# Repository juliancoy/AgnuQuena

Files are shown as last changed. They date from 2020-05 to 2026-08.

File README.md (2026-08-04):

This is an OpenScad design of a Quena Andian flute. Is is parametric and split into 3 parts to allow to fit any 3d printer size.

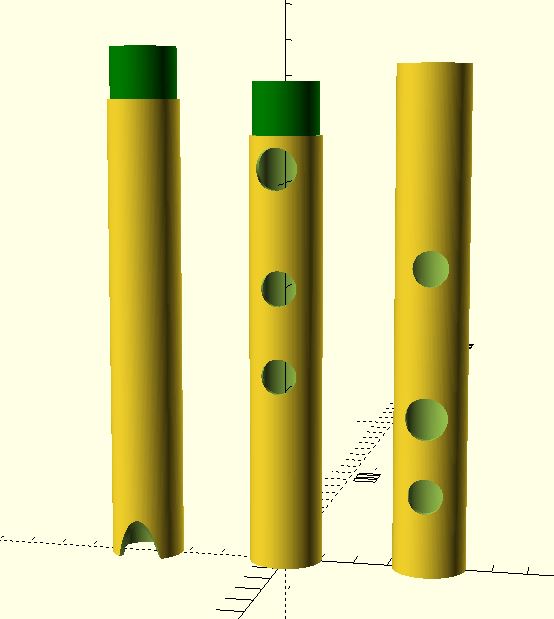
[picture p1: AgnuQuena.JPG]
GitHub Logo


## Production generation

The production flute is generated deterministically from
`designs/quena.json`. See [QUENA_GENERATION.md](QUENA_GENERATION.md) for the
rapid-iteration, validation, and STL export workflow.

```sh
make quena-generate
make quena-validate
make quena-export
```

To regenerate, validate, and slice the complete quena layout plus two-color and
single-filament print-in-place case variants for the Bambu Lab P1S, run:

```sh
make print-slice
```

The retained source projects, printable `.gcode.3mf` files, and plain G-code
are named `Quena`, `QuenaCase`, and `QuenaCaseSingleFilament` under
`bambu-slice-output/`, alongside job-specific slicer results and SHA-256
manifests. The printable 3MF files already contain the validated slice and open
directly in Preview, so printing does not depend on the desktop Slice action.
The two-color case confines all artwork
to the first `0.20 mm` layer, reducing the job to one material change. The
single-filament case preserves the
recessed logo and mandala/flourish engraving but omits the separate inlay mesh,
second filament, and prime tower. It is the unattended option for a printer
equipped with one AMS HT. Bambu Studio 2.8's mixed external/AMS mapping supports
assigning black filament 2 to External and yellow filament 1 to the AMS HT.
The printer prompts for the one manual external-path handoff before continuing
from the AMS. The source is pinned in the `BambuStudio` submodule and the scripts
invoke the native Linux CLI built directly from that revision. Run
`make bambu-studio-setup` once after cloning; its Ubuntu 24.04 Docker builder
keeps the large incremental build cache inside the ignored submodule build
directory, installs a project-local runtime, and installs the pinned official
Bambu networking plugin under the user's BambuStudio data directory. Existing
plugin files are retained in a timestamped backup. `make print-export` performs
the same canonical geometry and project generation without slicing, while
`make case-single-export` rebuilds only the single-filament case project.

## Browser CFD lab

`run.py` starts the lab and its automated Chrome test environment as two
Docker containers. Running it without arguments is equivalent to `up`.

```sh
python3 run.py
python3 run.py status
python3 run.py test --require-webgpu
python3 run.py down
```

The lab is served at <http://127.0.0.1:4173/acoustics.html>. Selenium listens
on port 4444, and its noVNC browser is available at <http://127.0.0.1:7900>.
The startup smoke test loads the lab through the Docker network, verifies its
CFD controls, advances the WebGPU clock when available, and writes a screenshot
to `build/selenium/acoustic-lab.png`.

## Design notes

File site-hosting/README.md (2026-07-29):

# Acoustic Lab hosting wrapper

This minimal Next application packages the static browser tools in `website/`
for OpenAI Sites. Before building or publishing, copy the current `website/`
contents into this directory's `public/` folder and copy
`.openai/hosting.json` into `.openai/hosting.json`.

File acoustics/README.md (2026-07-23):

# Vulkan Acoustic Simulation

This folder contains acoustic simulation tools for the quena geometry.

## Calibrated 1D Model

`quena_1d.py` reads the generated production manifest by default (with an
OpenSCAD fallback for historical work), applies calibrated per-hole corrections
where available, and writes pitch estimates that can be compared with
tune-check measurements.

Run the current worktree model:

```sh
python3 acoustics/quena_1d.py
```

To bypass the generated manifest and inspect a standalone SCAD file:

```sh
python3 acoustics/quena_1d.py --manifest "" --scad Quena.scad
```

Run a measured historical geometry and fit its correction from the saved
tune-check note:

```sh
python3 acoustics/quena_1d.py --commit a36f6253471d --fit-correction
```

Outputs:

- `acoustics/out/quena_1d_simulation_worktree.csv`
- `acoustics/out/quena_1d_simulation_worktree.json`

Use `--label current` or another label to choose a different output suffix.

This is the practical pitch estimator. It is calibrated and one-dimensional, so
it should be treated as an engineering model rather than a full fluid/acoustic
solver.

## Printable Materials

All acoustic runners accept `--material`. Available defaults:

```sh
python3 acoustics/quena_3d.py --list-materials
```

Supported built-in profiles include `pla`, `abs`, `petg`, `tpu`, `cf-pla`,
`cf-petg`, and `nylon`; `carbon-fiber` aliases to `cf-pla`. The material model
changes the simulated print result:
length scale, bore and tone-hole dimensional bias, end/tone-hole corrections,
and FDTD damping. It does not pretend the air column is made of plastic; for
stiff printed flutes the plastic mainly matters through geometry, edge finish,
wall loss, and compliance.

Example:

```sh
python3 acoustics/quena_3d.py --material petg --label petg_current
```

## Assembled Printed Shape

Export the fitted-together print shape and the matching internal air volume:

```sh
python3 acoustics/export_assembled.py
```

This writes ignored generated artifacts:

- `acoustics/out/assembled_quena.stl`
- `acoustics/out/assembled_air.stl`
- `acoustics/out/assembled_validation.json`

Use the air STL for the closest current simulation of the fitted print:

```sh
python3 acoustics/quena_3d.py --material abs --air-stl acoustics/out/assembled_air.stl --steps 4096 --label abs_air_stl_generated
```

The air STL is the acoustic domain. The plastic STL is useful for inspection and
validation, but simulating the plastic shell as the fluid domain would be wrong.

Current ABS assembled-air validation:

| note | predicted hz | predicted cents | measured cents |
| --- | ---: | ---: | ---: |
| G4 | 418.0214 | +111.27 | -1.3 |
| A4 | 422.4296 | -70.55 | -1.3 |
| B4 | 477.7188 | -57.6 | -41.3 |
| C5 | 513.1936 | -33.6 | -21.3 |
| D5 | 592.3994 | +14.88 | -11.3 |
| E5 | 675.0935 | +41.09 | -1.3 |
| F#5 | 771.279 | +71.7 | -21.3 |
| G5 | 751.0543 | -74.3 | -1.3 |

The assembled-air run currently has median absolute prediction error of
`55.8 cents` and RMS error of `65.5 cents` against the saved tune-check
measurements. Treat it as the current 3D fluid baseline for ABS in the exact
printed air shape, not yet as a final tuning oracle.

## 2D FDTD Cross-Section

`quena_2d.py` runs a scalar-pressure finite-difference simulation on a
longitudinal bore cross-section. The distal end and the active tone-hole opening
are pressure-release boundaries; the bore walls are reflective.

Run all notes:

```sh
python3 acoustics/quena_2d.py --label current
```

Run a single note while tuning model parameters:

```sh
python3 acoustics/quena_2d.py --note B4 --steps 32768
```

Outputs:

- `acoustics/out/quena_2d_simulation_current.csv`
- `acoustics/out/quena_2d_simulation_current.json`

This is a real time-domain simulation, but still a 2D approximation. It ignores
azimuthal tone-hole shape and external radiation impedance, so use it for
directional checks before treating it as a final tuning authority.

## 3D FDTD Bore Model

`quena_3d.py` is the CPU reference 3D fluid/acoustic simulation. It creates a
cylindrical bore air mask from the SCAD dimensions, uses reflective bore walls,
applies pressure-release openings for the distal end or active fingering hole,
injects an impulse, records receiver pressure, and reports FFT peaks.

Run all notes with the default coarse grid:

```sh
python3 acoustics/quena_3d.py --label current
```

Run a single note for faster iteration:

```sh
python3 acoustics/quena_3d.py --note B4 --steps 8192 --label b4_smoke
```

Outputs:

- `acoustics/out/quena_3d_simulation_current.csv`
- `acoustics/out/quena_3d_simulation_current.json`

The default grid is intentionally coarse enough to run on CPU. Reduce
`--cell-mm` only after validating runtime and memory use; 3D FDTD must keep
`--courant` below `1/sqrt(3)`.

### Breath source and environmental inputs

The 3D runner accepts physical breath parameters rather than an arbitrary
"soft/hard" label. Flow and jet area determine velocity and dynamic pressure;
vertical/lateral angles and lip distance determine source coupling. Air
temperature and relative humidity alter sound speed and therefore resonance.

```sh
python3 acoustics/quena_3d.py --note A4 --steps 8192 \
  --flow-l-min 12 --jet-width-mm 8 --jet-thickness-mm 1.2 \
  --vertical-angle-deg 15 --lateral-angle-deg 5 --lip-distance-mm 8 \
  --temperature-c 22 --relative-humidity-pct 50 --label a4_breath
```

This remains a linear scalar-pressure source-coupling model. It is appropriate
for resonance and sensitivity screening: breath quantity changes amplitude and
angle changes coupling, while temperature/humidity change frequency through
sound speed. It does **not** resolve the turbulent lip jet, vortex shedding,
self-sustained oscillation, pitch bending, or register selection. Those require
a transient compressible CFD model with the exterior mouthpiece/lip geometry;
do not interpret this source model as that CFD calculation.

Current coarse-grid validation:

```sh
python3 acoustics/quena_3d.py --steps 8192 --label current_coarse
```

This run completes on CPU and writes per-note pitch estimates. At the current
coarse resolution it is useful as a real 3D reference simulation, not a final
tuning oracle: the July 2026 comparison run had median absolute error around
`45 cents` and RMS error around `63 cents` for the idealized cylinder. The
assembled-air STL run above is the better baseline when checking the fitted
printed shape.

## Vulkan FDTD Setup

The Vulkan path is still a setup path for a future 3D FDTD simulation.

The compute kernel is `shaders/fdtd.comp`. It updates a scalar pressure field on
a 3D grid with a solid mask for printed material boundaries. Boundary neighbors
inside the solid mask mirror the center cell pressure, which approximates a hard
reflective wall.

Run the setup pass:

```sh
python3 acoustics/vulkan_fdtd.py --stl Quena.stl
```

That compiles the Vulkan shader with `glslc`, reads the STL bounds, checks the
3D Courant stability condition, and writes
`acoustics/out/simulation_manifest.json`.

Next implementation steps:

1. Voxelize the STL into the shader's `SolidMask` buffer.
2. Allocate Vulkan storage buffers for previous/current/next pressure fields.
3. Dispatch the compute shader for each timestep and record receiver samples.
4. FFT the receiver impulse response and compare peaks with measured notes.

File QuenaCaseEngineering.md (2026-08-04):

# Quena Case Engineering Notes

## Captive Print-in-Place Hinge

The complete case prints as two already-assembled moving bodies. Both shell
exteriors lie flat on the bed with the case opened exactly 180 degrees. The lid
carries a continuous axle captured inside seven closed bottom bearings, while
eight interleaved lid webs support the axle and limit axial travel. No pin
insertion, snap assembly, support material, or post-print joining is required.

Critical dimensions:

- Hinge axis: centered on the case seam
- Integral axle diameter: `4.6 mm`
- Axle print flat: `0.60 mm`
- Bearing exterior: fully round with a `0.40 mm` body-side starter web
- Outer axle ends: enclosed by solid, fully round `9.8 mm` lid barrels with
  `1.2 mm` clean-face overhangs
- Bearing bore: `5.20 mm`
- Radial print-in-place clearance: `0.30 mm`
- Bearing outside diameter: `9.8 mm`
- Minimum concentric bearing wall: `2.30 mm`
- Circular bore bridge span: `5.20 mm`
- Independent bearing width: `14.5 mm`
- Gap between alternating features: `1.0 mm`
- Rear-shell inset: `4.6 mm`
- Rear projection: `5.2 mm`
- Shell-edge gap in the print pose: `0.60 mm`

The axle retains its printer-facing flat inside the running bearings, while the
bearing exterior and both visible end barrels are fully round. Each stator
intersects the rear shell directly, without a rectangular backer that could
break its circular silhouette. The solid end barrels replace the exposed
D-flat axle stubs and tie directly into the outer
lid webs. A shallow tangent web connects the bearing's first layers back to the
body without entering the running bore. Each unsupported axle interval is only
one segment pitch (`15.5 mm`). The fully circular `5.20 mm` bore closes over a
short bridge span that remains below the validated `6.0 mm` support-free limit.
The radial clearance is deliberately larger than an assembled running fit
because the first motion must break minor extrusion wisps without welding the
joint.
Twist the two shell strips gently in opposite directions after cooling, then
exercise the hinge through its full travel before operating the latch.

## Nub-and-Knuckle Clasp

The latch is integral to the two case halves; there is no separately printed
latch. It follows the simplest molded harmonica-case pattern: two lid tongues
carry pronounced inward nubs, and the bottom front wall carries two matching
recesses. Pulling at the centered textured thumb zone releases the two points
progressively as the lid is opened.
Critical dimensions:

- Two `18 x 1.6 x 15.9 mm` lid cantilever tongues at `x=-72, +72 mm`,
  with `4.4 mm` widened bonded root haunches continuing toward the bed-facing
  lid back and an `11.5 mm` free flex span below them.
- `2.0 mm` nub/dimple radius and `1.25 mm` nub projection.
- `0.85 mm` bottom-wall recess depth.
- `0.40 mm` required release travel.
- Five low rounded grip ribs in a centered `30 mm` thumb zone.

The two nub spheres are added after all tongue, hinge, and ornament relief
booleans. No subtractive operation is allowed to flatten or hollow either nub.

Run `python3 tools/model_latch_snap.py --material all` to screen actuation. For
ABS, each tongue moves `0.40 mm`; the cantilever model predicts `0.73%` root
strain, `8.7-17.5 N` release force per point, and `4.13x` strain margin. The
conservative simultaneous two-point bound is `17.5-34.9 N`, though normal
opening should unzip the points progressively. All screened materials pass.
The full case is the physical check for closing alignment, user access, and
release force; no separate coupon meshes are maintained.

## Retention Features

Tube retention is built into five short curved sections of the bottom channel
border: two on Tube 1, two on Tube 2, and one on the mouthpiece. Each section
is `14 mm` long, rises `3.0 mm` above the stored-part centerline, and overlaps
the continuous bed by `0.4 mm` so it exports as one structural body. The
resulting normal-tube aperture has `0.34 mm` diametral interference: enough for
a light positive snap without forcing the entire channel length over the part.

The same border geometry, expanded by `0.25 mm`, is removed from the lid. This
keeps the closed outside envelope unchanged and prevents the raised bottom
features from loading the lid. Relative to the prior meshes, the bottom gains
`667.8 mm3` while the lid loses `686.8 mm3`; at `1.04 g/cm3` ABS density the
complete case changes by only `-0.02 g`.

The later round hinge-end enclosure adds about `1.05 g` net relative to that
pre-retention reference, keeping the complete case within `0.4%` of its former
mass while eliminating the exposed axle ends.

Run `python3 tools/simulate_case_inversion.py` for the inverted load screen.
At the default `42 g` stored mass, the closed case passes a `10 g` load with a
`7.4x` conservative latch-force margin. Physical insertion force, release
force, layer bonding, and fatigue still require a printed fit check.

## Channel Layout

Channel placement is based on the complete recess extents, including end and
connector clearance, rather than the nominal flute-part centers. This keeps
the recesses optically centered even though connector-bearing profiles are
asymmetric.

- P1 is a plain `241.25 mm` body. The `15 mm` tube-joint sleeve belongs to
  P2 and extends before its body, with the expanded case pocket on that end.
  Its closest assembled tone-hole edge is the D hole at `4.129 mm`; changing
  the breakpoint does not move any acoustically calibrated hole position.
- The long P1 recess is centered horizontally by its finished cut bounds.
- The short tube and mouthpiece recesses use equal `11.54 mm` left, middle, and
  right distribution gaps.
- Raised land between the two channel rows: `2.5 mm`.
- Raised perimeter land around the channel field: `2.5 mm` minimum.
- A single continuous `11.45 mm` bed forms the recesses and terminates `0.8 mm`
  beyond the nominal tube equator. The five localized snap-border sections
  extend that wrap to `3.0 mm`; there are no separate cantilever parts.

## Validation

Run:

```sh
python3 tools/render_case_assets.py --all-meshes
python3 tools/build_case_3mf.py
python3 tools/test_case_stls.py
python3 tools/test_case_browser.py
python3 tools/test_case_bambu.py
```

This checks:

- STL bounds and connected-component counts.
- Axle/bore clearance, concentric bearing wall, circular bridge span, alternating
  segment width, shell-edge bed gap, rear projection, axial web capture, and
  axle print flat, concentric bearing wall, starter web, and bed contact from the
  OpenSCAD parameters.
- The production STL contains exactly two watertight moving components, both
  touch `Z=0`, and the complete footprint stays inside `256 x 256 mm`.
- The bottom exterior retains a `14 mm` plan-view corner radius, `1.5 mm`
  bed-facing edge rounds, a border exactly `5 mm` inward, and three rendered
  mandalas with printable strokes and a two-layer recess floor.
- Closed clamshell solid overlap using OpenSCAD CSG intersection.
- Empty-case hinge sweep from `0` to `180` degrees around the actual hinge axis.
- Loaded hinge sweep over the same range using solid envelopes for all three
  flute parts, including connector bulges and transitions. The test repeats at
  18 combinations of the permitted axial, lateral, and lidward clearances.
- Chrome renders untransformed model-space STLs and checks their exact triangle
  BVHs at every whole-degree pose from `0` to `180`. A deliberate `4 mm`
  penetration must also register, proving that the detector is active.
- The browser keeps positive Z at the top of the view, lights both intentional
  friction-fit nub contacts while the case is closed, and removes those latch
  markers once the nubs release at `3 degrees`. Exact surface intersections
  elsewhere remain highlighted as line segments on the model.
- The browser loads the logo/title and mandala/flourish inlays as separate
  model-space meshes, using contrasting coral and gold materials rather than
  flattening either decoration into the blue shell material.
- The checksum-verified native Bambu Studio CLI opens and slices the project
  directly with the P1S profile, two ABS filaments, one colour change, and
  no generated support, brim, or skirt toolpaths. It checks that black is used
  only in the first `0.20 mm` layer and that the compact prime tower ends at
  `Z=0.2`.

The OpenSCAD and browser checks are required because Bullet/pybullet can miss
static concave mesh penetration and does not detect coplanar Z-fighting. The
browser therefore displays exact triangle contact separately from the two
intentional closed latch interferences. The browser regression caught a real
seven-point hinge collision at `25 degrees`; the lid relief now follows each
stator's complete circular envelope. A zero-depth hinge surface contact can be
visible without failing the rigid-envelope sweep; the failure threshold remains
`0.05 mm` of actual penetration.
The loaded sweep is a deterministic rigid-envelope interference screen. It does
not model flute bounce, elastic deformation, friction, wear, or latch failure;
inverted and shock retention remain separate engineering checks.

The larger shell's plan-view corner radius is `14 mm`. The alternating
axle-support tabs carry the same radius-to-width ratio into their shorter
visible profiles, producing an approximately `0.83 mm` base radius instead of
square shoulders. This proportional rounding does not expand the shallow
radial attachment land or alter the concentric bearing, bore, or
print-in-place clearance.

## Procedural Mandala and Flourish Panel

The lower panel in the open print pose carries three twelve-fold mandala
rosettes inside a rounded frame. Two symmetric vine-knot flourishes fill the
spaces between the rosettes. The design is generated entirely in
`QuenaCase.scad` from concentric rings, radial strokes, orbiting halos, curved
tendrils, and broad leaves, so it remains deterministic and scales with the
case rather than depending on another image asset. The frame centerline follows
the case outline exactly `5 mm` inward.

The single-filament body engraves the ornament `0.40 mm`, or two project
layers. The two-colour body instead uses a `0.20 mm` recess filled by the black
`QuenaCaseArtwork.stl` inlay. This preserves the case's face-down production
pose, reduces the two-colour job to one material change, and leaves at least
`2.40 mm` of solid roof. All
nominal strokes are `0.90 mm` wide, exceeding two line widths for the `0.4 mm`
nozzle. The recesses close without slicer-generated support, and the inlay
meets their floors exactly. The outside plan-view corner radius is `14 mm`,
and `1.5 mm` rounds soften both exposed bed-facing shell edges while retaining
flat first-layer contact. Internal fit, hinge, and latch geometry are unchanged.

## Two-Colour Case Artwork

`EurasianSynergyFlute_logo_2color.png` is the artwork source of truth. Running
`python3 tools/vectorize_case_logo.py` separates its original title and Eurasian
silhouette, removes details narrower than a `0.4 mm` nozzle, and deterministically
generates `generated/case_logo_title.svg`, `generated/case_logo_map.svg`, and
their measured source dimensions. The upper open-pose panel uses those traced
vectors rather than a substituted font or a hand-redrawn map.

The title remains `190 mm` wide and the map `84 mm` wide. A `0.84` vertical
scale fits the composition inside the long upper face while retaining at least a
`2.0 mm` rounded-edge margin. The single-filament logo remains engraved
`0.60 mm` deep for visibility. In the two-colour body, both logo and ornament
inlays are exactly one `0.20 mm` layer deep. Their tops meet the recess floors
exactly, so the black and yellow ABS fuse across a full planar interface.

The traced logo is rotated 180 degrees in the CAD source so it reads normally
when viewed through the base shell's exterior face, while remaining upright on
the upper panel like the display of an open laptop. It is not reflected, which
would reverse both the title and continent. The mandala and flourish inlay
shares the lid's `lid_in_print_pose()` transform and occupies the lower panel.
`QuenaCaseArtwork.stl` combines both black inlays, so they are translated and
aligned with `QuenaCaseTwoColorPrintInPlace.stl`; no slicer positioning is
required.

`QuenaCase.3mf` is the canonical native Bambu Studio two-colour P1S project.
`tools/build_case_3mf.py` creates its archive through the checksum-verified
project-local Bambu Studio CLI, then applies the locked placement and reviewed
print contract. It contains one assembly with:

- `QuenaCaseTwoColorPrintInPlace.stl` assigned to yellow ABS / AMS slot 1.
- `QuenaCaseArtwork.stl` assigned to black ABS / AMS slot 2.
- `0.20 mm` layers, two `0.42-0.45 mm` wall lines, two-layer top and bottom
  skins, `10%` rectilinear infill combined across compatible layers, and
  `0.15 mm` elephant-foot compensation. This reduces repeated perimeter and
  sparse-infill travel without changing the one-layer artwork, hinge, latch,
  or print-in-place clearances.
- The straight OpenSCAD shell is `0.827 mm`, the deposited envelope of the
  `0.42 + 0.45 mm` perimeter pair after Bambu's rounded-extrusion overlap at a
  `0.20 mm` layer height. The original `3 mm` structural margin remains local
  to the hinge, rim, and both friction-fit latch receivers; the mating nubs and
  their intentional closed-case collision are unchanged.
- The bottom channel bed meets the shell's inner face with a `0.04 mm`
  modeling overlap. Its printed edge is aligned with the perimeter, removing
  the open moat that previously separated the two regions.
- A continuous `0.827 mm` lip rises locally to `3.0 mm` past each tube
  centerline while the main bed and shell retain their original height. Its
  opening provides the light snap without isolated clips; the lid is lowered
  locally with `0.25 mm` matching relief around the complete profile.
- Broad outer walls run at a conservative `120 mm/s`, below the P1S standard
  profile's `200 mm/s`; the inherited `50%` small-perimeter rule keeps hinge,
  latch, and ornament details at `60 mm/s`.
- Supports, brims, and skirts disabled; a compact `20 mm` prime tower with a
  `1 mm` brim is limited to the active colour layer and ends at `Z=0.2`.

The two-colour slice has one material transition. With only one AMS HT,
map black filament 2 to External and yellow filament 1 to the AMS HT in the
Bambu Studio 2.8 send dialog. Its mixed external/AMS workflow pauses for the
operator to unload the unpowered external path, then continues from the AMS.
It is still not an unattended two-colour configuration,
but the single-layer artwork minimizes the intervention and purge waste.

`bambu-slice-output/QuenaCase.gcode.3mf` contains the validated slice and opens
directly in Preview. Use it for printing so the desktop application does not
need to run the unstable Linux GUI Slice action.

`QuenaCaseSingleFilament.3mf` is the one-material alternative. It contains only
`QuenaCasePrintInPlace.stl` on filament 1, so the logo and mandala/flourish
remain visible as recessed engraving instead of flush black inlays. It retains
the same placement, layers, walls, infill, and support-free contract while
disabling multi-material mode and the prime tower. Its validated G-code must
contain no second-tool request.

The project places the complete assembly at `X=2.275..253.725 mm` and its
sliced paths at `Y=70.787..184.735 mm`, clear of the P1S front-left exclusion
region and with the prime-tower area behind it. Inspect the first two sliced
layers before printing: only the first-layer artwork should be black, every
artwork island must bond to the yellow case at layer two, and the `0.60 mm`
hinge shell gap must remain open.

The automated Bambu slice produces `96` layers and one colour change. The
current estimate is about `111.39 g` of model ABS (`110.30 g` yellow and
`1.08 g` black), `112.06 g` including purge and prime-tower material, and
`4 h 30 min`; estimates can vary with Bambu Studio releases and printer
calibration.

## Print Practice

`QuenaCasePrintInPlace.stl` is the deeply engraved single-filament production
geometry. `QuenaCaseTwoColorPrintInPlace.stl` is the shallow-recess body for
`QuenaCase.3mf`; use `QuenaCaseSingleFilament.3mf` for a recessed one-material
finish. Both STLs are already oriented with both exterior backs on `Z=0`, side by
side, and the hinge captured at 180 degrees. Its `252.9 x 113.9 mm` footprint
fits the nominal `256 x 256 mm` bed with about `1.6 mm` of X margin per
side when centered. Disable brims, skirts, and automatic support; confirm the
retained P1S plate placement and printer-specific exclusion zones before
starting the full print.

`QuenaCaseBottom.stl` and `QuenaCaseLid.stl` are the canonical model-space
components used by both the browser and engineering validation. The combined
print-in-place STL remains separate because its lid must be rigidly rotated
180 degrees into the build-plate pose.

Use normal first-layer compensation rather than globally shrinking the hinge
gap. Avoid elephant-foot expansion into the 0.60 mm shell separation. After
the bed and part are fully cool, flex the two halves oppositely along the hinge
line to break any wisps, then rotate progressively from the center toward both
ends. Do not drive a blade or wire through the bearings.

- `QuenaCasePrintInPlace.stl`: `72294` triangles,
  `252.9 x 113.9 x 19.3 mm`, `2` connected components.
- `QuenaCaseTwoColorPrintInPlace.stl`: `72310` triangles,
  `252.9 x 113.9 x 19.3 mm`, `2` connected components.
- `QuenaCaseArtwork.stl`: `44502` triangles, `243.8 x 105.3 x 0.2 mm`,
  `31` connected artwork components.
- `QuenaCaseBottom.stl`: `17342` triangles,
  `252.9 x 61.3 x 19.3 mm`, `1` connected component.
- `QuenaCaseLid.stl`: `54960` triangles,
  `252.9 x 62.4 x 19.3 mm`, `1` connected component.
- `QuenaCaseLatch.stl`: `56.0 x 8.3 x 11.6 mm`.
- `QuenaCaseAssembly.stl`: `72294` triangles, `252.9 x 62.4 x 28.8 mm`.
- Closed overlap check: empty intersection.
- Hinge sweep check: passes from `0` to `180` degrees around
  `(0.00, -28.35, 14.40)`.
- Loaded hinge sweep: passes all `18` clearance-limit poses for all `3` stored
  part envelopes from `0` to `180` degrees.

Verify first-motion release, free rotation, and acceptable play on the full
print. If it fuses, adjust the canonical radial or axial clearance and
rerender; do not hand-fit the case or add a hidden slicer-only gap.

## Selective Output

Running `python3 tools/render_case_assets.py` produces only the primary
`QuenaCasePrintInPlace.stl`. Run it with `--list` to show every other mesh and
review sheet; those outputs are optional and selected with repeatable `--mesh`
and `--view` arguments. `--all-meshes` and `--all-views` are reserved for full
validation. Coupon outputs are not generated.

## Nine-View Review

Run:

```sh
python3 tools/render_case_assets.py --all-views
```

This regenerates:

- `QuenaCaseAssembly_9views.png`
- `QuenaCasePrintInPlace_9views.png`
- `QuenaCaseLidHingeCloseup_9views.png`

Each sheet is a 3x3 camera sweep at `1500 x 1101 px`. Use these views to catch
framing, hinge, and latch regressions before slicing.

The lid-hinge close-up sheet targets the integral axle, alternating support
webs, D-flat, and both axle ends without whole-part auto-framing.

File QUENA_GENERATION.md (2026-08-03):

# Quena generation workflow

`designs/quena.json` is the canonical production specification for the flute.
Do not hand-edit generated dimensions in `Quena.scad`,
`generated/quena_parameters.scad`, or `generated/quena_manifest.json`.

## Rapid iteration

1. Edit `designs/quena.json`.
2. Regenerate and validate the derived parameters:

   ```sh
   make quena-generate
   make quena-validate
   ```

3. Inspect the geometry and tuning report.
4. Export the three production components:

   ```sh
   make quena-export
   ```

The STL files and their SHA-256 production manifest are written under
`build/quena/`.

Use this command in CI or before slicing to detect generated files that do not
match the specification:

```sh
python3 tools/generate_quena.py --check
```

## What the generator owns

The generator derives:

- tuned acoustic and printable tube lengths;
- component split locations and maximum print height;
- lower-hand hole positions from the layout policy;
- measured-compensation hole diameters;
- OpenSCAD parameters shared by the flute and case;
- ergonomic hole diameter and width limits;
- hole edge, inter-hole ligament, and print-height validation;
- a machine-readable geometry and validation manifest.

The compensation model uses the low-frequency open-tone-hole shunt fit identified
in the specification, calibrated independently for each hole from the saved
prototype measurements. Each calibrated opening is solved directly against its
12-TET `target_note`; no legacy reference geometry defines the tuning target.
Calibration stores the printed prototype's actual acoustic hole position, so a
later body-length correction cannot rescale and invalidate that measurement.
When a guided run uses the removable headstock as a global tuner, its calibration
also stores `global_pitch_offset_cents`. The generator removes that shared offset
before fitting the hole correction, keeping base-note adjustment separate from
interval tuning.
Diameter results are rounded to the configured production increment. The fit is
based on Antoine Lefebvre's *Computational
Acoustic Methods for the Design of Woodwind Instruments*, equations 2.3.1–2.3.2:
<https://escholarship.mcgill.ca/concern/theses/0z708w835>.

## Design boundaries

Generation is deterministic and constraint-driven; it is not a substitute for
prototype measurement. After changing bore dimensions, material, hole profile,
or the lower-hand layout:

1. print a prototype;
2. record a guided tuning sample;
3. update the calibration measurements in the specification;
4. regenerate and compare the complete fingering set.

Use the fast one-dimensional model during iteration. Reserve the slower 2D/3D
models and physical prints for shortlisted geometries.

The current generator performs constrained geometric derivation and
measurement-calibrated diameter compensation. It does not claim to be a global
optimizer of the full fingering lattice. A future optimizer should consume this
same specification and manifest, evaluate all fingerings with a validated
transfer-matrix model, and return candidate specifications through the same
manufacturing checks.

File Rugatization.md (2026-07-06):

# Rugatization

## Goal

Raise the quality of AgnuQuena measurements by adding two connected systems:

1. A Vulkan-powered 3D acoustic simulation pipeline.
2. A Git-history measurement analysis pipeline that compares design dimensions with noted output pitches.

The simulation does not count as solved until it can produce testable pitch estimates from actual model geometry and compare those estimates with printed/measured results.

## Acceptance Criteria

- The tool can take `Quena.stl` or another generated STL as input.
- The STL is converted into a 3D solid/air simulation grid.
- A Vulkan compute shader runs a time-domain acoustic simulation over that grid.
- The simulation exports pressure samples from one or more receiver points.
- FFT or equivalent spectral analysis identifies candidate resonant frequencies.
- Simulated frequencies are compared against measured pitches from commit history and tuning files.
- Results are reproducible from scripts checked into the repo.

## Implementation Plan

1. Define simulation acceptance criteria and expected outputs.

   The pipeline should take an STL, simulate an impulse, output receiver pressure data, estimate resonance peaks, and compare those peaks against measured notes/history data.

2. Implement STL voxelization.

   Convert STL triangles into a 3D grid with a `solid_mask` buffer. This is the next hard blocker: without it, the shader has no real flute geometry.

3. Build Vulkan compute dispatch.

   Allocate `previous_pressure`, `current_pressure`, `next_pressure`, and `solid_mask` buffers. Dispatch the FDTD compute shader for many timesteps and ping-pong pressure buffers.

4. Add acoustic source and receiver modeling.

   Place a source near the mouthpiece or active edge. Place receivers near the bore end and optionally near tone holes. Export pressure samples as CSV first.

5. Analyze simulated response.

   Run FFT and peak detection over receiver impulse responses. Report candidate resonances in Hz and cents from expected notes.

6. Tie simulation results to Git-history measurements.

   Extend the measurement-history tooling so each commit/configuration can be associated with simulated pitch estimates and printed pitch measurements.

7. Validate against known measured pitches.

   Use pitch notes already present in `Quena.scad` and `Fife/tuning.csv` as the first benchmark. The first useful win condition is directional accuracy: geometry changes should move predicted resonances the same way measured prints do.

## Current State

- `tools/compare_measurements.py` extracts geometry, hole positions, pitch comments, and tuning CSV measurements across Git history.
- `measurements/history/*.csv` contains generated history-analysis outputs.
- `acoustics/quena_1d.py` provides a calibrated 1D bore model that reads SCAD/history geometry, emits pitch estimates, and compares them with tune-check measurements.
- `acoustics/quena_2d.py` runs a numpy-based 2D FDTD cross-section and exports FFT-derived pitch estimates for each fingering.
- `acoustics/quena_3d.py` runs a CPU 3D FDTD cylindrical-bore fluid/acoustic simulation and exports FFT-derived pitch estimates.
- `acoustics/materials.py` provides PLA, ABS, PETG, TPU, nylon, and carbon-fiber composite print profiles for dimensional bias, edge correction, wall loss, and damping.
- `acoustics/export_assembled.py` exports and validates fitted assembled plastic and internal-air STL files for exact-shape acoustic runs.
- `acoustics/quena_3d.py --air-stl acoustics/out/assembled_air.stl` voxelizes the fitted internal-air STL and runs the 3D fluid simulation on that exact air shape.
- `acoustics/shaders/fdtd.comp` contains a Vulkan compute shader for 3D scalar-pressure FDTD.
- `acoustics/vulkan_fdtd.py` compiles the shader, probes Vulkan devices, reads STL bounds, checks Courant stability, and writes a simulation manifest.
- Important geometry caveat: the current `Quena.stl` is a printable layout with separated parts, not a single assembled acoustic air column. Use `acoustics/export_assembled.py` to generate the fitted-together plastic and internal-air STLs for simulation.

## Latest ABS Exact-Shape Run

Command:

```sh
python3 acoustics/export_assembled.py
python3 acoustics/quena_3d.py --material abs --air-stl acoustics/out/assembled_air.stl --steps 4096 --label abs_air_stl_generated
```

Validation:

- Plastic STL: watertight, one component, 7188 faces.
- Internal-air STL: watertight, one component, 4406 faces.
- ABS assembled-air 3D FDTD: median absolute prediction error `55.8 cents`, RMS error `65.5 cents`.

Readings:

| note | predicted hz | predicted cents | measured cents |
| --- | ---: | ---: | ---: |
| G4 | 418.0214 | +111.27 | -1.3 |
| A4 | 422.4296 | -70.55 | -1.3 |
| B4 | 477.7188 | -57.6 | -41.3 |
| C5 | 513.1936 | -33.6 | -21.3 |
| D5 | 592.3994 | +14.88 | -11.3 |
| E5 | 675.0935 | +41.09 | -1.3 |
| F#5 | 771.279 | +71.7 | -21.3 |
| G5 | 751.0543 | -74.3 | -1.3 |

This is a real 3D fluid run over the fitted internal air volume. It is still a
coarse CPU model, so the result should guide the next simulation improvements
rather than directly drive hole changes.

## Progress Checklist

- [x] Define simulation acceptance criteria and expected outputs.
- [x] Add CPU 1D, 2D, and 3D reference simulations that export pitch estimates.
- [x] Export fitted assembled plastic and internal-air STLs.
- [x] Voxelize the assembled internal-air STL for CPU 3D FDTD.
- [x] Add acoustic source/receiver modeling and pressure sample export in CPU 2D/3D simulations.
- [x] Analyze simulated response into resonant pitch estimates.
- [x] Tie simulation results to Git-history and saved measurement CSVs.
- [x] Validate against known recorded pitch measurements.
- [ ] Implement STL voxelization into the Vulkan shader's `SolidMask` grid.
- [ ] Build Vulkan compute dispatch and pressure-buffer ping-pong.

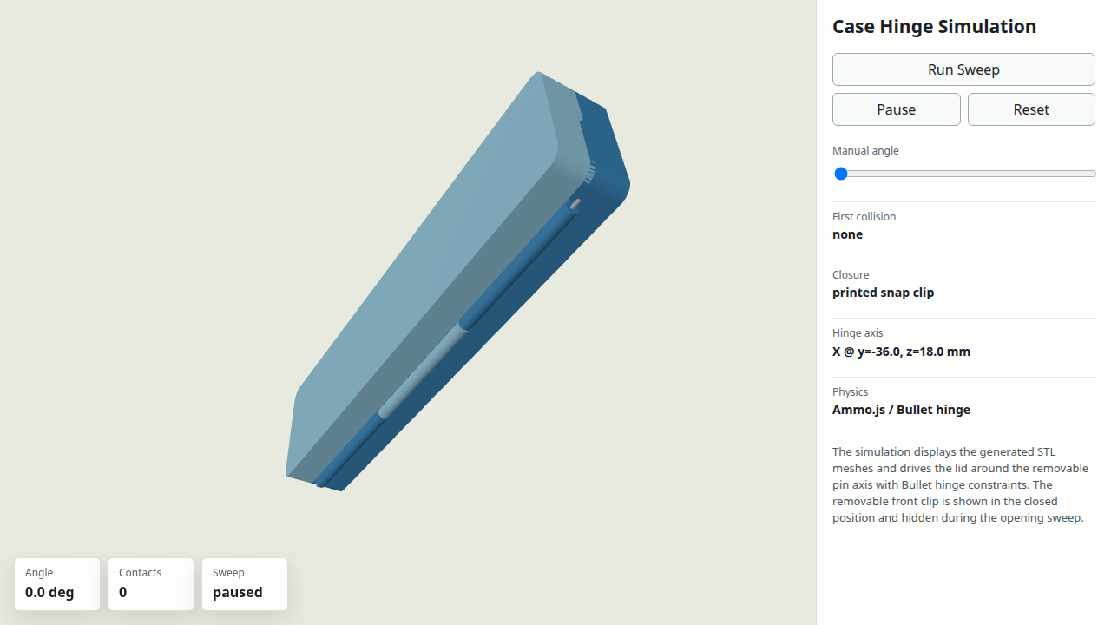
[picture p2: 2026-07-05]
website_hinge_sim.png

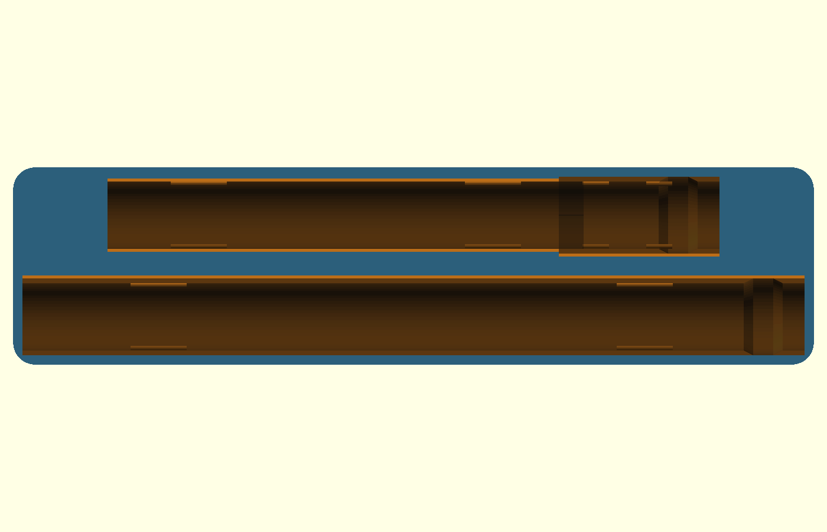
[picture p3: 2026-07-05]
retention_review_top.png

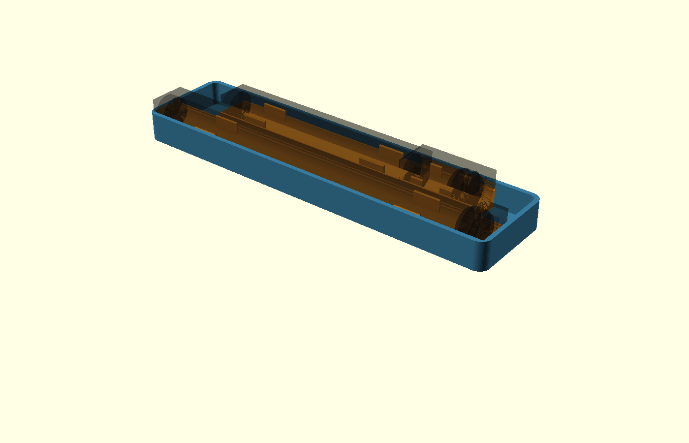
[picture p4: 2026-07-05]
retention_review_oblique.png

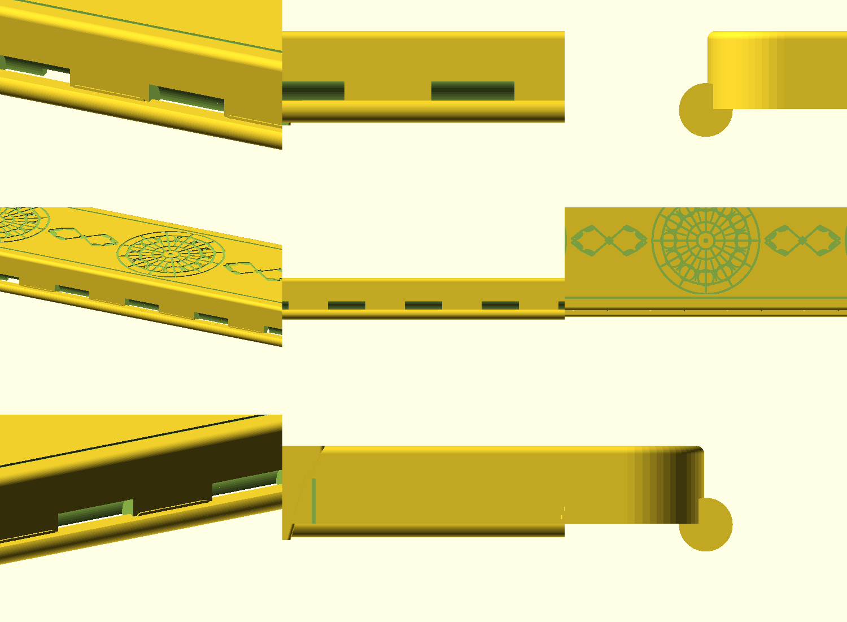
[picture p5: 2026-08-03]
QuenaCaseLidHingeCloseup_9views.png

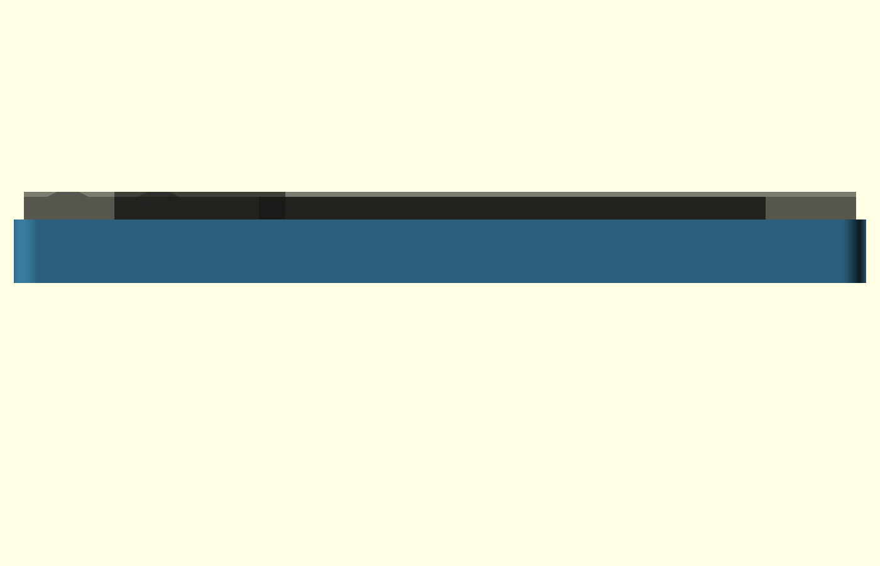
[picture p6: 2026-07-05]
retention_review_front.png

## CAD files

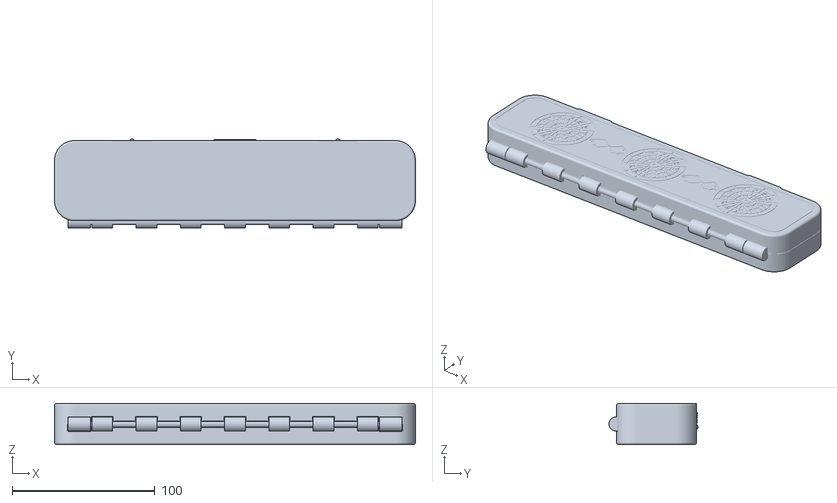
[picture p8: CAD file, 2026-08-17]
site-hosting/public/assets/QuenaCaseAssembly.stl
252.8 x 62.4 x 28.8

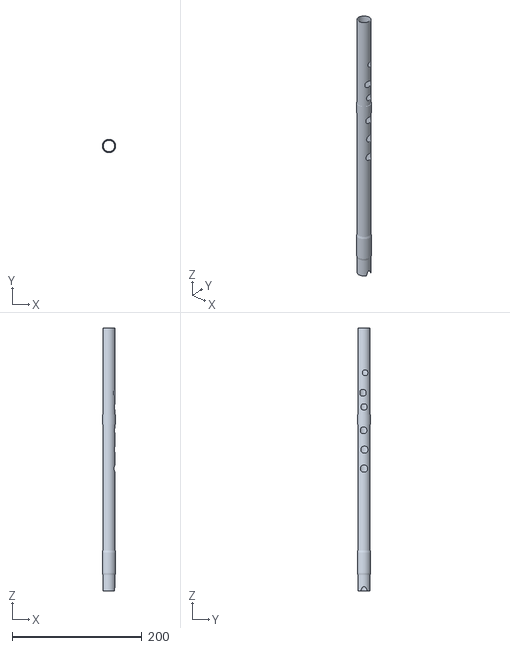
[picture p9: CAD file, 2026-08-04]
site-hosting/public/assets/QuenaProductionAssembly.stl
20.7 x 20.7 x 404.7

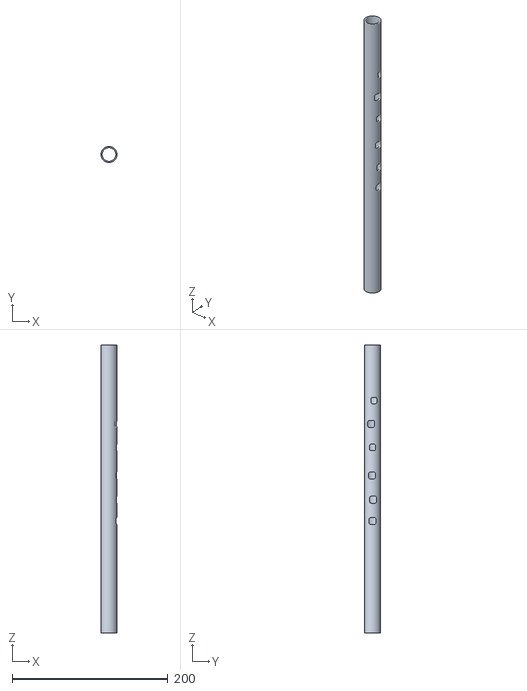
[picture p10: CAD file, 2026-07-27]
analysis/quena_structural.stl
20.5 x 20.5 x 369.3

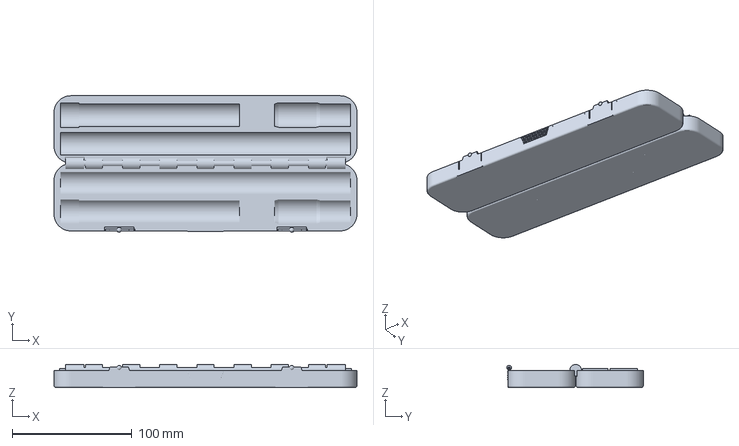
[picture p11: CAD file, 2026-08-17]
bambu-slice-output/QuenaCase.3mf
252.9 x 113.9 x 19.3 mm

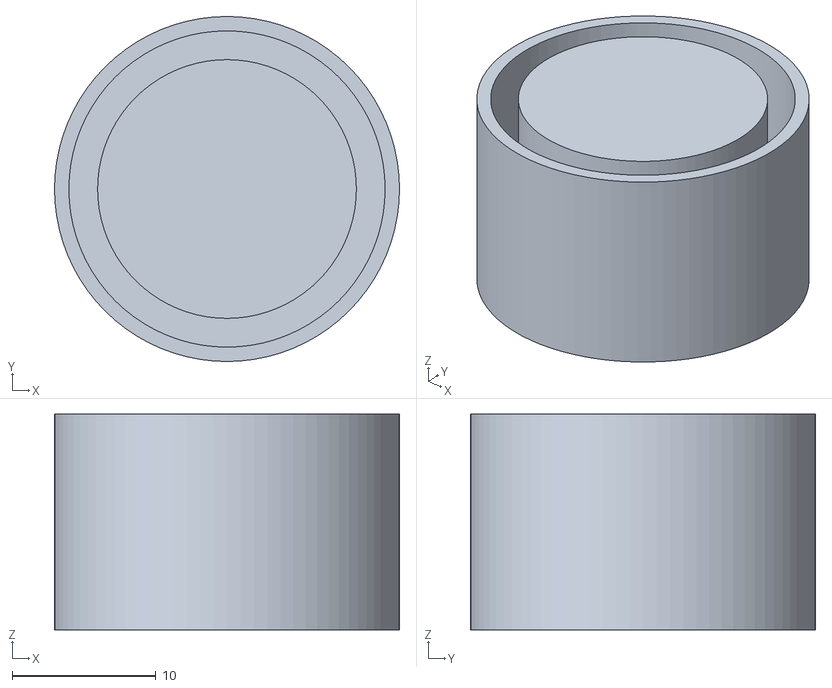
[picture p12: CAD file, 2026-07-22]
Fife/EndCap.stl
24.0 x 24.0 x 15.0

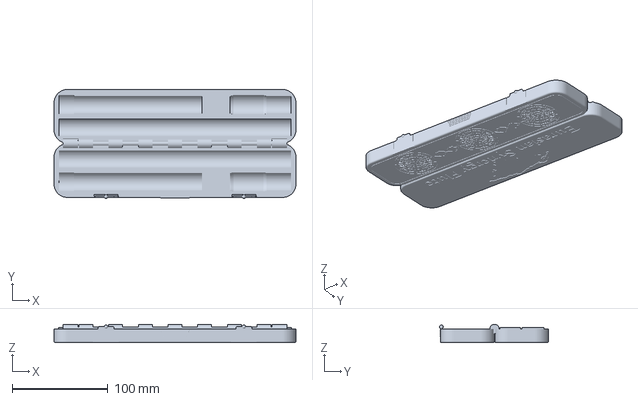
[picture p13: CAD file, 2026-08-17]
QuenaCaseSingleFilament.3mf
252.9 x 113.9 x 19.3 mm

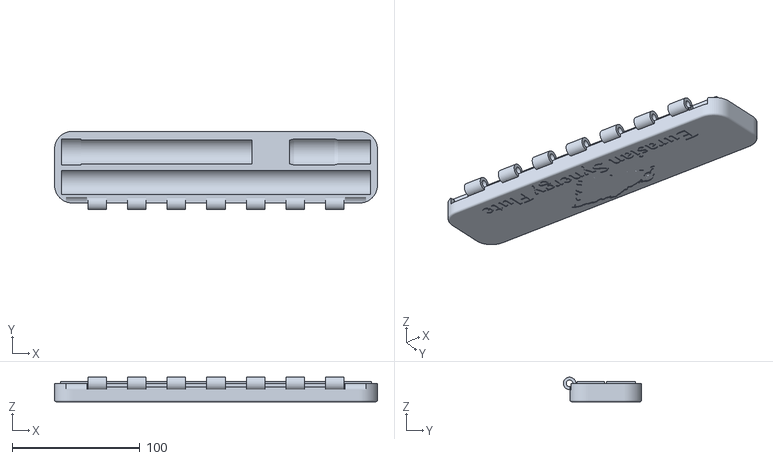
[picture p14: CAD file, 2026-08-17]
website/assets/QuenaCaseBottom.stl
252.8 x 61.3 x 19.3

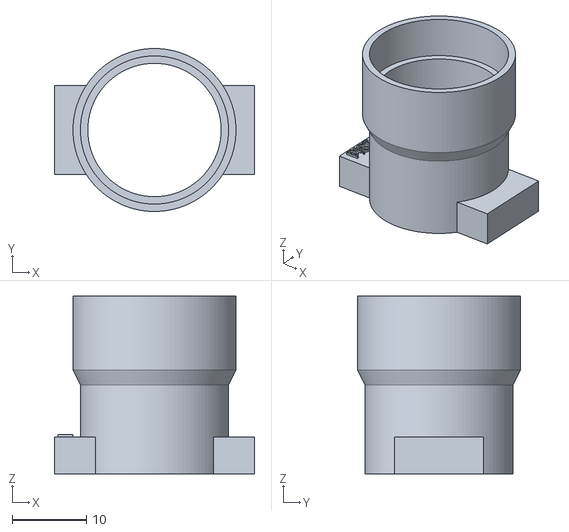
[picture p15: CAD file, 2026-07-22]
Fife/PipeExtension.stl
27.0 x 22.0 x 24.0

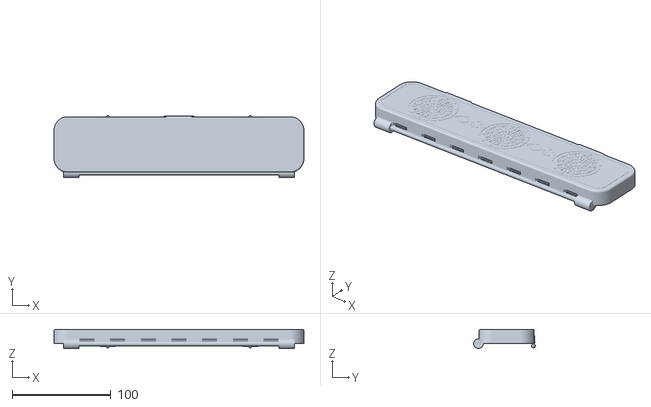
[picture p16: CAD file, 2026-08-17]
QuenaCaseLid.stl
252.8 x 62.4 x 19.3

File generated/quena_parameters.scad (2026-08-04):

// GENERATED FILE. DO NOT EDIT.
// Source: designs/quena.json
// Regenerate: python3 tools/generate_quena.py
generated_design_id = "agnuquena-g";
generated_spec_sha256 = "7a5be4d5fcc11ae19114969f2a0dae9f556bb1a15ad0b820fda51e613e63caec";

quena_facet_count = 100.0;
shell_width = 0.8;
id = 17.5;
od = 19.1;
hd = 18.3;
taper = 0.0;
ido = 17.5;
odo = 19.1;
mouthpiece_total_length = 30.0;
unacoustic_length = 6.0;
mouthpiece_active_length = 24.0;
pitch_raise_cents = -11.74;
length_tuning_scale = 1.00680433493;
acoustic_length = 398.69451663;
zadj = -8.0;
total_height = 404.69451663;
angled_transition_z = 3.0;
accent_ring_z = 0.0;
mouthpiece_overlap = 32.0;
tube_joint_overlap = 15.0;
tube_joint_connector_part = 2.0;
non_mouthpiece_acoustic_length = 374.69451663;
tube_part_1_length = 241.25;
tube_part_2_length = 133.44451663;
part_lengths = [tube_part_1_length, tube_part_2_length];
part_start = [0, tube_part_1_length];
tube_spacing_factor = 0.6;
e = 0.004;
connector_radial_clearance = 0.0;
insert_z_tolerance = 0.4;
tone_hole_axial_scale = 1.0;
tone_hole_circumferential_scale = 1.0;
tone_hole_corner_ratio = 0.4;
lower_tube_hole_angle_spread = 12.0;
lower_tube_first_hole_offset = 11.924;
lower_tube_hole_spacing = 30.0855;

tone_hole_a_z = 305.753;
tone_hole_a_angle = -12.0;
tone_hole_a_diameter = 9.0;
tone_hole_b_z = 275.0;
tone_hole_b_angle = 12.0;
tone_hole_b_diameter = 10.63;
tone_hole_c_z = 253.174;
tone_hole_c_angle = 0.0;
tone_hole_c_diameter = 9.75;
tone_hole_d_z = 217.111742057;
tone_hole_d_angle = 5.0;
tone_hole_d_diameter = 10.5;
tone_hole_e_z = 187.480771622;
tone_hole_e_angle = -5.0;
tone_hole_e_diameter = 11.1;
tone_hole_fs_z = 158.390902136;
tone_hole_fs_angle = 0.0;
tone_hole_fs_diameter = 11.13;

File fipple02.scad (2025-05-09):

use <Quena.scad>;

$fa = 0.1;
$fs = 0.1;

/********************************************************/
// Mikael Fernstrom
// 2014-06-11
// fipple02.scad
// Mouthpiece for a flute or whistle, including fipple	
/********************************************************/


shell_width = 2.25;
id = 17.5;  // internal diameter at mouthpiece
od = id + shell_width*2;  // outer diameter at mouthpiece
ov = 15;    // part overlap sleeve
ov_male = ov - 0.8; // z space left between merges. leave some gap to make sure they can close completely

Dhalf = (id + od) / 4;

e = 0.01;
Douter = od/2;
Dinner = id/2-0.5;
TotalHeight = 42;
BodyHeight = 25;
WindowHeight = 18;
WindowWidth = 11.2;
WindowDepth = 1;
LipGap = 5;
LipRadius = 12;
fastAirHeight = 10; 
fastAirWidth = 11.2;
fippleBaseHeight = 2;
BladeHeight = 17;
BladeWidth = 20;
BladeDepth = 7;
BladeDepthTop = 0.4;


mouthpiece_active_length = 22.5; // distance from mouthpiece start to active edge

// shows the expected active length of the mouthpiece
// the top of this cylinder should be at the wind active edge
//%translate([Dhalf, 0,]) cylinder(r = 3, h = mouthpiece_active_length+ov_male);

module MainBody()
{
	difference()
	{ 
		// main tubular section
		cylinder(r = Douter, h = TotalHeight);
		translate([0,0,-e]) 
		cylinder(r = Dinner, h = BodyHeight+e*2);
		// this is the tone hole
		translate([Douter - LipGap, -(WindowWidth / 2) , TotalHeight - BodyHeight - WindowHeight/2]) 
		cube([LipGap,WindowWidth, WindowHeight]);  
		// Window 
		translate([Douter-LipGap, -fastAirWidth / 2 , BodyHeight]) 
		cube([WindowDepth,fastAirWidth, WindowHeight+e]);
		// lip-part cut out
		rotate(90, [1,0,0])
		translate([-1 * TotalHeight / 4, TotalHeight, -1 * Douter])
		cylinder(r = LipRadius, Douter * 2);
	}
}

module BladeBase()
{
	difference()
	{
		translate([0,0,BodyHeight - fastAirHeight - fippleBaseHeight ])
		cylinder(fippleBaseHeight,Dinner,Dinner);
		rotate([0,0,180])
		translate([-(Douter - LipGap),-Dinner, BodyHeight - fastAirHeight - fippleBaseHeight- e ])
		cube([2*Dinner,2*Dinner,fippleBaseHeight+e*2]);
	}
}


module Blade()
{
    difference(){
        intersection(){
            translate([Douter - LipGap + WindowDepth/2 + BladeDepth/2, BladeWidth/2, BodyHeight-WindowHeight])
            {
                rotate(90,[1,0,0])
                rotate(90,[0,0,1])
                linear_extrude(height = BladeWidth)
                {
                    polygon([ [0,0], [0,BladeDepth], [BladeHeight, BladeDepth/2 + BladeDepthTop/2], [BladeHeight, BladeDepth/2 - BladeDepthTop/2] ]);
                }
            }
            cylinder(h=100, r=Douter);
        }
        
        translate([0,0,BodyHeight-WindowHeight+BladeHeight+1])
        scale([1,2,1])
        rotate([0,90,0])
        cylinder(h=100, r=3, center=true);
        
        
        translate([0, 0, BodyHeight-WindowHeight-e])
        cylinder(h=BladeHeight-5, r1=Dinner, r2=Dinner -3);
        
    }
}


translate([0,0,ov_male]){
    MainBody();
    //BladeBase();
    Blade();
    
}

difference(){
    cylinder(h = ov_male, r = Dhalf);
    translate([0,0,-e])
    cylinder(h = ov_male+2*e, r = Dinner);
}

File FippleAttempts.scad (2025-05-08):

cyl_cut_width = 10;
cut_angle = 30;
cut_height = 3;

module cyl_cut(){
    intersection(){
        union(){
            cylinder(h = cut_height, d2=id-e, d1=od+0.1);
            difference(){
                cylinder(h = cut_height, d=od+0.1);
                cylinder(h = cut_height, d1=id-e, d2=od+0.1);
                
            }
        }
        translate([hd/2, 0,0])
        cylinder(h = 100, d = 15, center=true);
    }
}
            
channel_shell_width = 1.5;
channel_scale_x = 0.4;
channel_scale_y = 2;
channel_length = 26;
module fipple_channel(){
    translate([hd/2, 0, channel_length/2])
    scale([channel_scale_x,channel_scale_y,1])
    cylinder(h = channel_length+0.1, r1 = 3, r2=1.72, center=true);
}

channel_straight = 10;
channel_overlap  = 10 + e;
module fipple(){
    translate([hd/2, 0, channel_straight/2])
    scale([channel_scale_x,channel_scale_y,1])
    cylinder(h = channel_straight, r = 4+channel_shell_width, center=true);

    hull($fn=80){
        // channel positive upper
        translate([hd/2, 0, channel_length/2 + channel_straight/2])
        scale([channel_scale_x,channel_scale_y,1])
        cylinder(h = channel_length-channel_straight, r1 = 4+channel_shell_width, r2 = 3+channel_shell_width, center=true);
        // end stop
        translate([0,0,20])
        cylinder(d = od + e, h = shell_width, center=true);
    }
    
    difference(){
        mouthpiece();
        translate([0,0,20/2-e])
        cylinder(d = od + 0.02, h = 20, center=true);
    }
}

channel_width = 20;
channel_height = 4;
connexion_size = 2;
aoa = 8;
    
module fipple_wide(){
    translate([hd/2-1, 0, 0])
    rotate([0,aoa,0])
    difference(){
        union(){
            
            // initial channel
            hull(){
                translate([0,channel_width/2,channel_straight/2])
                cylinder(h = channel_straight, d = channel_height, center=true);
                translate([0,-channel_width/2,channel_straight/2])
                cylinder(h = channel_straight, d = channel_height, center=true);
            }
            //expansive channel outer shell
            hull(){
                translate([0,channel_width/2,channel_straight + channel_overlap/2])
                cylinder(h = channel_overlap, d = channel_height, center=true);
                translate([0,-channel_width/2,channel_straight + channel_overlap/2])
                cylinder(h = channel_overlap, d = channel_height, center=true);
                // end circle
                rotate([0,-aoa,0])
                translate([-hd/2+1,0,mouthpiece_size-connexion_size-1])
                cylinder(h=connexion_size, d = od, center=true);
            }
            
            // supporting structures
            translate([-1.8,0,channel_straight])
            scale([1,20,1])
            rotate([0,-aoa-8,0])
            cylinder(h =2, d =1, center=true);
        }
        // initial channel
        hull(){
            translate([0,channel_width/2,-e])
            cylinder(h = channel_straight+channel_overlap+e*3, d = channel_height-shell_width, center=true);
            translate([0,-channel_width/2,-e])
            cylinder(h = channel_straight+channel_overlap+e*3, d = channel_height-shell_width, center=true);
        }
        // expanding channel
        
        hull(){
            translate([0,channel_width/2,channel_straight+channel_overlap/2-e])
            cylinder(h = channel_overlap+e*3, d = channel_height-shell_width, center=true);
            translate([0,-channel_width/2,channel_straight+channel_overlap/2-e])
            cylinder(h = channel_overlap+e*3, d = channel_height-shell_width, center=true);
                // end circle
                rotate([0,-aoa,0])
            translate([-id/2,0, mouthpiece_size-connexion_size-1])
            cylinder(h=connexion_size+e, d = id, center=true);
            
        }
        
        // hole cut
        translate([1,0,channel_straight+channel_overlap+7])
        rotate([0,30,0])
        hull(){
            translate([0,-4,0])
            cylinder(h = 6, r = 2, center=true);
            translate([0,4,0])
            cylinder(h = 6, r = 2, center=true);
            
            // expand the outflow area
            translate([7,0,-3])
            rotate([0,90,0])
            cylinder(h = 1, r = 6, center=true);
        }
        
        

        
    }  
    
    
    // inner sleeve
    difference(){
        difference() {
            color("green") translate([0, 0, mouthpiece_size-accent_ring_z]) sleve_wide((mouthpiece_size) / total_height, friction_expand_default);
            translate([0,0,-1])
            tube_negative();
        }
        translate([0,0,channel_straight/2-e])cylinder(d = od + 0.02, h = channel_straight, center=true);
        translate([0,0,channel_straight+5]) cyl_cut();
    }
}

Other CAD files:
bambu-slice-output/QuenaCaseSingleFilament.gcode.3mf
LowWhistle.scad
Fife/EndCap.scad
Fife/PipeExtension.scad
Quena.3mf
Quena.scad
Quena.stl
QuenaCase.scad
QuenaCaseArtwork.stl
QuenaCaseBottomViewer.stl
QuenaCaseEngraving.stl
QuenaCaseLogo.stl
QuenaCasePrintInPlace.stl
QuenaCaseTwoColorPrintInPlace.stl
QuenaPart1.stl
QuenaPart2.stl
QuenaPart3.stl
Quena_fit_test.stl
ToneHoleErgonomicCoupon.scad
ToneHoleErgonomicCoupon.stl
acoustics/assembled_air.scad
acoustics/assembled_quena.scad
analysis/quena_structural.scad
bambu-slice-output/Quena.3mf
bambu-slice-output/Quena.gcode.3mf
bambu-slice-output/QuenaCase.gcode.3mf
fipple02.stl
generated/case_logo_dimensions.scad
q_mouthpiece.stl
site-hosting/public/assets/QuenaCaseArtwork.stl
site-hosting/public/assets/QuenaCaseBottomViewer.stl
site-hosting/public/assets/QuenaCaseEngraving.stl
site-hosting/public/assets/QuenaCaseLatch.stl
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

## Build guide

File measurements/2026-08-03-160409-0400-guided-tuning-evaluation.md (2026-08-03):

# Axial retune from the 2026-08-03 guided measurement

The headstock was pulled out slightly for this run. The two detector medians put
G4 at **+9.79 cents**, so that value is treated as the global headstock/tube
offset. Hole corrections use each note's interval error relative to G4; applying
the full absolute error would incorrectly tune the adjustable base length into
every tone-hole position.

Detector consensus is the geometric mean of the Loiacono and librosa median
frequencies. With effective length `L = 343000 / (2f)`, the requested distal
shift is:

`target effective length * (1 - 2^(-interval error cents / 1200))`.

| Hole | Consensus error | Error relative to G4 | Requested distal shift | Generated physical Z |
|---|---:|---:|---:|---:|
| A | +60.93 c | +51.14 c | +3.753 mm | 305.753 mm |
| B | +15.49 c | +5.70 c | +1.142 mm | 275.000 mm |
| C | +69.84 c | +60.05 c | +11.174 mm | 253.174 mm |
| D | +69.81 c | +60.01 c | +9.949 mm | 217.112 mm |
| E | +76.00 c | +66.21 c | +9.761 mm | 187.481 mm |
| F# | +73.41 c | +63.62 c | +8.362 mm | 158.391 mm |

B is placed 0.704 mm farther toward the foot than its unconstrained acoustic
solution so the rounded-square B/C cuts retain the required 12 mm axial
ligament. Its solved diameter therefore increases slightly from 10.50 to
10.63 mm to preserve the pitch target.

The A hole was subsequently reduced from 10.10 to 9.00 mm and moved 7.592 mm
toward the mouthpiece. The paired diameter/position change preserves its fitted
pitch while making the lowest hole smaller and easier to reach.

The tube-1/tube-2 break moves from 222.50 to 232.25 mm. This is required to keep
the shifted D hole on tube 1 with a 10 mm part-end ligament while retaining a
sub-240 mm print height. The resulting generated limits are 12.10 mm minimum
axial ligament, 10.13 mm minimum part-end ligament, and 239.85 mm maximum print
height.

The saved calibration records the measured frequency and the +9.79-cent global
offset separately. The generator removes that offset before fitting each hole,
so future body-length changes do not erase the distinction between adjustable
global tuning and note-specific interval tuning.

The G5/G4 octave remains about 15.5 cents wide. Tone-hole relocation cannot
correct that open-fingering register error; verify it again on the new print
before changing the notch or blowing edge.

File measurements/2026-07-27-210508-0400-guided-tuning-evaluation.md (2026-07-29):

# 2026-07-27 guided tuning evaluation

Source: `2026-07-27-210508-0400-guided-tuning.csv`

The run contains 24 accepted 250 ms blocks per note and two pitch estimates per
block. The calibration frequency below is the median of all 48 accepted
frequency estimates for each note. Loiacono and librosa agree on the direction
and approximate size of every error.

| Note | Calibration Hz | Target Hz | Error |
|---|---:|---:|---:|
| G4 | 397.41 | 392.00 | +23.7 cents |
| A4 | 455.58 | 440.00 | +60.3 cents |
| B4 | 499.31 | 493.88 | +18.9 cents |
| C5 | 541.78 | 523.25 | +60.3 cents |
| D5 | 614.29 | 587.33 | +77.7 cents |
| E5 | 687.98 | 659.26 | +73.8 cents |
| F#5 | 776.02 | 739.99 | +82.3 cents |
| G5 | 810.74 | 783.99 | +57.8 cents |

The preceding, incomplete 21:04 run independently showed the same sharp
direction from G4 through E5. The complete run is used for calibration.

## Applied correction

G4 is the closed-hole body-length reference. Its +23.7-cent error changes
`pitch_raise_cents` from +12.00 to -11.74, increasing acoustic length from
393.265 mm to 398.695 mm.

Each first-register tone hole is calibrated from the printed prototype's actual
acoustic position, opening diameter, and measured median frequency. The
generator now solves that opening directly against its explicit 12-TET
`target_note`.

| Hole | Printed diameter | Corrected diameter | Printed physical z | Corrected physical z |
|---|---:|---:|---:|---:|
| A | 9.03 mm | 7.90 mm | 298.000 mm | 302.000 mm |
| B | 10.26 mm | 10.30 mm | 268.000 mm | 272.000 mm |
| C | 8.86 mm | 7.98 mm | 238.000 mm | 242.000 mm |
| D | 10.00 mm | 8.95 mm | 201.933 mm | 207.163 mm |
| E | 10.00 mm | 9.42 mm | 170.918 mm | 177.719 mm |
| F# | 10.00 mm | 9.37 mm | 143.604 mm | 150.029 mm |

The holes were moved down-axis, away from the mouthpiece, to recover comfortable
opening sizes without raising their modeled pitch. The lower-hand holes move
4 mm, while the upper-hand holes move 5.23–6.80 mm. The break remains at 222 mm.
The rounded production openings remain within 0.14 cent of their modeled
targets. Manufacturing validation passes with 19.07 mm minimum axial ligament,
10.73 mm minimum part-end ligament, and 229.60 mm maximum print height.

## Remaining physical acceptance

G5 is 34.1 cents sharper relative to G4 than a pure octave. Body length and
first-register tone-hole corrections do not establish whether this is
mouthpiece geometry or the breath/tilt operating point. No mouthpiece change is
justified from one upper-register note. Print the corrected geometry, repeat the
one-octave run for first-register confirmation, and then record a controlled
two-octave run before changing the notch or blowing edge.

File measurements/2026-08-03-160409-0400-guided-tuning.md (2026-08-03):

# Guided tuning measurement

Sample rate: 44100 Hz
Requested duration per note: 6 seconds
Gesture: grade loud to soft and tilt the flute back to forth.

| Note | Algorithm | Blocks | Median Hz | Target Hz | Median cents | Stability | Range cents |
|---|---|---:|---:|---:|---:|---:|---:|
| G4 | loiacono | 24 | 394.10 | 392.00 | +9.3 | 11.7 | -16.3 to +37.9 |
| G4 | librosa | 24 | 394.34 | 392.00 | +10.3 | 10.3 | -6.8 to +51.5 |
| A4 | loiacono | 24 | 456.76 | 440.00 | +64.7 | 17.1 | +28.8 to +84.2 |
| A4 | librosa | 24 | 454.77 | 440.00 | +57.1 | 8.7 | +50.6 to +81.2 |
| B4 | loiacono | 24 | 498.28 | 493.88 | +15.4 | 10.4 | -2.7 to +44.5 |
| B4 | librosa | 24 | 498.36 | 493.88 | +15.6 | 6.8 | +8.2 to +32.1 |
| C5 | loiacono | 24 | 543.66 | 523.25 | +66.2 | 34.0 | -87.9 to +100.0 |
| C5 | librosa | 24 | 545.93 | 523.25 | +73.5 | 33.8 | -91.2 to +94.4 |
| D5 | loiacono | 24 | 611.44 | 587.33 | +69.6 | 8.9 | +56.1 to +96.5 |
| D5 | librosa | 24 | 611.55 | 587.33 | +70.0 | 5.1 | +61.9 to +81.0 |
| E5 | loiacono | 24 | 688.02 | 659.26 | +73.9 | 8.9 | +58.4 to +92.2 |
| E5 | librosa | 24 | 689.66 | 659.26 | +78.1 | 9.5 | +63.2 to +95.3 |
| F#5 | loiacono | 24 | 771.10 | 739.99 | +71.3 | 7.0 | +63.4 to +93.0 |
| F#5 | librosa | 24 | 772.99 | 739.99 | +75.5 | 5.0 | +70.1 to +92.7 |
| G5 | loiacono | 24 | 796.01 | 783.99 | +26.3 | 15.5 | -29.0 to +36.2 |
| G5 | librosa | 24 | 795.21 | 783.99 | +24.6 | 14.3 | -26.0 to +38.0 |

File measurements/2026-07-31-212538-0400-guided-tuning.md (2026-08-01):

# Guided tuning measurement

Sample rate: 44100 Hz
Requested duration per note: 6 seconds
Gesture: grade loud to soft and tilt the flute back to forth.

| Note | Algorithm | Blocks | Median Hz | Target Hz | Median cents | Stability | Range cents |
|---|---|---:|---:|---:|---:|---:|---:|
| G4 | loiacono | 24 | 392.50 | 392.00 | +2.2 | 22.5 | -50.8 to +74.1 |
| G4 | librosa | 24 | 393.85 | 392.00 | +8.2 | 23.8 | -9.8 to +81.9 |
| A4 | loiacono | 24 | 452.59 | 440.00 | +48.9 | 17.5 | +23.1 to +90.3 |
| A4 | librosa | 24 | 454.31 | 440.00 | +55.4 | 29.4 | -87.4 to +68.7 |
| B4 | loiacono | 24 | 500.72 | 493.88 | +23.8 | 13.8 | -2.6 to +54.6 |
| B4 | librosa | 24 | 500.19 | 493.88 | +22.0 | 6.5 | +11.6 to +35.8 |
| C5 | loiacono | 24 | 539.62 | 523.25 | +53.3 | 33.7 | -93.6 to +93.5 |
| C5 | librosa | 24 | 542.18 | 523.25 | +61.5 | 35.5 | -64.7 to +81.5 |
| D5 | loiacono | 24 | 609.56 | 587.33 | +64.3 | 12.3 | +34.8 to +83.0 |
| D5 | librosa | 24 | 609.33 | 587.33 | +63.7 | 3.8 | +59.9 to +74.1 |
| E5 | loiacono | 24 | 680.73 | 659.26 | +55.5 | 17.6 | +11.6 to +77.3 |
| E5 | librosa | 24 | 678.10 | 659.26 | +48.8 | 6.9 | +42.4 to +77.9 |
| F#5 | loiacono | 24 | 762.07 | 739.99 | +50.9 | 8.3 | +42.0 to +73.6 |
| F#5 | librosa | 24 | 762.30 | 739.99 | +51.4 | 4.1 | +46.7 to +62.0 |
| G5 | loiacono | 24 | 794.58 | 783.99 | +23.2 | 30.6 | -46.9 to +69.1 |
| G5 | librosa | 24 | 793.03 | 783.99 | +19.9 | 12.6 | -42.0 to +23.8 |

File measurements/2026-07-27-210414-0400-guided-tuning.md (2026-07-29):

# Guided tuning measurement

Sample rate: 44100 Hz

Requested duration per note: 6 seconds

Gesture: grade loud to soft and tilt the flute back to forth.

| Note | Algorithm | Blocks | Median Hz | Target Hz | Median cents | Stability | Range cents |
|---|---|---:|---:|---:|---:|---:|---:|
| G4 | loiacono | 24 | 397.45 | 392.00 | +23.9 | 13.0 | +1.9 to +44.0 |
| G4 | librosa | 24 | 397.05 | 392.00 | +22.2 | 8.7 | +17.7 to +62.9 |
| A4 | loiacono | 24 | 458.17 | 440.00 | +70.1 | 9.0 | +35.2 to +78.8 |
| A4 | librosa | 24 | 459.42 | 440.00 | +74.8 | 11.1 | +22.3 to +82.6 |
| B4 | loiacono | 24 | 503.93 | 493.88 | +34.9 | 12.5 | +6.2 to +63.3 |
| B4 | librosa | 24 | 504.49 | 493.88 | +36.8 | 13.1 | +1.3 to +65.4 |
| C5 | loiacono | 24 | 543.76 | 523.25 | +66.6 | 38.8 | -69.5 to +79.5 |
| C5 | librosa | 24 | 545.00 | 523.25 | +70.5 | 37.5 | -65.2 to +82.2 |
| D5 | loiacono | 24 | 614.81 | 587.33 | +79.2 | 9.9 | +64.7 to +99.5 |
| D5 | librosa | 24 | 616.19 | 587.33 | +83.0 | 5.3 | +73.2 to +92.5 |
| E5 | loiacono | 14 | 692.21 | 659.26 | +84.5 | 9.4 | +67.8 to +99.5 |
| E5 | librosa | 14 | 694.68 | 659.26 | +90.6 | 3.8 | +81.4 to +99.0 |
| F#5 | loiacono | 0 | -- | 739.99 | -- | -- | -- |
| F#5 | librosa | 0 | -- | 739.99 | -- | -- | -- |
| G5 | loiacono | 0 | -- | 783.99 | -- | -- | -- |
| G5 | librosa | 0 | -- | 783.99 | -- | -- | -- |
| A5 | loiacono | 0 | -- | 880.00 | -- | -- | -- |
| A5 | librosa | 0 | -- | 880.00 | -- | -- | -- |
| B5 | loiacono | 0 | -- | 987.77 | -- | -- | -- |
| B5 | librosa | 0 | -- | 987.77 | -- | -- | -- |
| C6 | loiacono | 0 | -- | 1046.50 | -- | -- | -- |
| C6 | librosa | 0 | -- | 1046.50 | -- | -- | -- |
| D6 | loiacono | 0 | -- | 1174.66 | -- | -- | -- |
| D6 | librosa | 0 | -- | 1174.66 | -- | -- | -- |
| E6 | loiacono | 0 | -- | 1318.51 | -- | -- | -- |
| E6 | librosa | 0 | -- | 1318.51 | -- | -- | -- |
| F#6 | loiacono | 0 | -- | 1479.98 | -- | -- | -- |
| F#6 | librosa | 0 | -- | 1479.98 | -- | -- | -- |
| G6 | loiacono | 0 | -- | 1567.98 | -- | -- | -- |
| G6 | librosa | 0 | -- | 1567.98 | -- | -- | -- |

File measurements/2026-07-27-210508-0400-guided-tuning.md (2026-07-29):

# Guided tuning measurement

Sample rate: 44100 Hz

Requested duration per note: 6 seconds

Gesture: grade loud to soft and tilt the flute back to forth.

| Note | Algorithm | Blocks | Median Hz | Target Hz | Median cents | Stability | Range cents |
|---|---|---:|---:|---:|---:|---:|---:|
| G4 | loiacono | 24 | 397.67 | 392.00 | +24.9 | 13.0 | -0.5 to +48.3 |
| G4 | librosa | 24 | 397.39 | 392.00 | +23.7 | 5.5 | +11.1 to +33.8 |
| A4 | loiacono | 24 | 454.33 | 440.00 | +55.5 | 18.6 | +7.7 to +84.9 |
| A4 | librosa | 24 | 455.87 | 440.00 | +61.3 | 4.7 | +48.0 to +72.2 |
| B4 | loiacono | 24 | 499.00 | 493.88 | +17.9 | 12.0 | -12.8 to +45.5 |
| B4 | librosa | 24 | 499.99 | 493.88 | +21.3 | 17.6 | -10.5 to +95.0 |
| C5 | loiacono | 24 | 542.32 | 523.25 | +62.0 | 25.7 | -55.4 to +89.7 |
| C5 | librosa | 24 | 541.66 | 523.25 | +59.9 | 5.6 | +46.8 to +79.8 |
| D5 | loiacono | 24 | 615.62 | 587.33 | +81.4 | 17.3 | +38.9 to +97.8 |
| D5 | librosa | 24 | 614.12 | 587.33 | +77.2 | 8.1 | +50.8 to +84.0 |
| E5 | loiacono | 24 | 687.93 | 659.26 | +73.7 | 14.6 | +35.8 to +98.2 |
| E5 | librosa | 24 | 688.28 | 659.26 | +74.6 | 6.6 | +55.4 to +84.3 |
| F#5 | loiacono | 24 | 774.02 | 739.99 | +77.8 | 11.5 | +56.9 to +98.5 |
| F#5 | librosa | 24 | 777.08 | 739.99 | +84.7 | 4.1 | +73.4 to +91.4 |
| G5 | loiacono | 24 | 810.42 | 783.99 | +57.4 | 19.0 | -26.9 to +83.5 |
| G5 | librosa | 24 | 811.23 | 783.99 | +59.1 | 9.9 | +15.5 to +67.6 |

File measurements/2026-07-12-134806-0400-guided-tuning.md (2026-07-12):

# Guided tuning measurement

Sample rate: 44100 Hz  
Requested duration per note: 6 seconds  
Gesture: grade loud to soft and tilt the flute back to forth.

| Note | Algorithm | Blocks | Median Hz | Target Hz | Median cents | Stability | Range cents |
|---|---|---:|---:|---:|---:|---:|---:|
| G4 | loiacono | 24 | 392.95 | 392.00 | +4.2 | 65.7 | -206.3 to +184.3 |
| G4 | librosa | 24 | 404.74 | 392.00 | +55.4 | 112.8 | +27.5 to +311.1 |
| A4 | loiacono | 24 | 440.08 | 440.00 | +0.3 | 162.4 | -300.0 to +275.0 |
| A4 | librosa | 24 | 525.00 | 440.00 | +305.8 | 129.5 | -177.2 to +305.8 |
| B4 | loiacono | 9 | 505.43 | 493.88 | +40.0 | 206.1 | -277.2 to +275.0 |
| B4 | librosa | 9 | 588.00 | 493.88 | +302.0 | 0.0 | +302.0 to +302.0 |
| C5 | loiacono | 0 | -- | 523.25 | -- | -- | -- |
| C5 | librosa | 0 | -- | 523.25 | -- | -- | -- |
| D5 | loiacono | 0 | -- | 587.33 | -- | -- | -- |
| D5 | librosa | 0 | -- | 587.33 | -- | -- | -- |
| E5 | loiacono | 0 | -- | 659.26 | -- | -- | -- |
| E5 | librosa | 0 | -- | 659.26 | -- | -- | -- |
| F#5 | loiacono | 0 | -- | 739.99 | -- | -- | -- |
| F#5 | librosa | 0 | -- | 739.99 | -- | -- | -- |
| G5 | loiacono | 0 | -- | 783.99 | -- | -- | -- |
| G5 | librosa | 0 | -- | 783.99 | -- | -- | -- |
| A5 | loiacono | 0 | -- | 880.00 | -- | -- | -- |
| A5 | librosa | 0 | -- | 880.00 | -- | -- | -- |
| B5 | loiacono | 0 | -- | 987.77 | -- | -- | -- |
| B5 | librosa | 0 | -- | 987.77 | -- | -- | -- |
| C6 | loiacono | 0 | -- | 1046.50 | -- | -- | -- |
| C6 | librosa | 0 | -- | 1046.50 | -- | -- | -- |
| D6 | loiacono | 0 | -- | 1174.66 | -- | -- | -- |
| D6 | librosa | 0 | -- | 1174.66 | -- | -- | -- |
| E6 | loiacono | 0 | -- | 1318.51 | -- | -- | -- |
| E6 | librosa | 0 | -- | 1318.51 | -- | -- | -- |
| F#6 | loiacono | 0 | -- | 1479.98 | -- | -- | -- |
| F#6 | librosa | 0 | -- | 1479.98 | -- | -- | -- |
| G6 | loiacono | 0 | -- | 1567.98 | -- | -- | -- |
| G6 | librosa | 0 | -- | 1567.98 | -- | -- | -- |

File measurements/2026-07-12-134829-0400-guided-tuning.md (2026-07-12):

# Guided tuning measurement

Sample rate: 44100 Hz  
Requested duration per note: 6 seconds  
Gesture: grade loud to soft and tilt the flute back to forth.

| Note | Algorithm | Blocks | Median Hz | Target Hz | Median cents | Stability | Range cents |
|---|---|---:|---:|---:|---:|---:|---:|
| G4 | loiacono | 24 | 392.90 | 392.00 | +4.0 | 92.5 | -179.0 to +275.0 |
| G4 | librosa | 24 | 418.76 | 392.00 | +114.3 | 88.4 | +27.3 to +311.1 |
| A4 | loiacono | 24 | 443.49 | 440.00 | +13.7 | 140.9 | -300.0 to +275.0 |
| A4 | librosa | 24 | 451.41 | 440.00 | +44.3 | 135.0 | -79.3 to +305.8 |
| B4 | loiacono | 24 | 490.39 | 493.88 | -12.3 | 95.0 | -198.3 to +275.0 |
| B4 | librosa | 24 | 511.18 | 493.88 | +59.6 | 127.3 | -170.5 to +302.0 |
| C5 | loiacono | 24 | 527.86 | 523.25 | +15.2 | 78.9 | -300.0 to +73.5 |
| C5 | librosa | 24 | 533.92 | 523.25 | +34.9 | 101.7 | -98.2 to +321.4 |
| D5 | loiacono | 24 | 596.51 | 587.33 | +26.9 | 93.2 | -300.0 to +275.0 |
| D5 | librosa | 24 | 594.92 | 587.33 | +22.2 | 103.7 | -173.7 to +303.8 |
| E5 | loiacono | 24 | 676.06 | 659.26 | +43.6 | 72.8 | -76.2 to +300.0 |
| E5 | librosa | 24 | 676.18 | 659.26 | +43.9 | 90.3 | +23.0 to +307.7 |
| F#5 | loiacono | 24 | 753.45 | 739.99 | +31.2 | 66.2 | -167.0 to +183.1 |
| F#5 | librosa | 24 | 753.57 | 739.99 | +31.5 | 85.6 | -91.8 to +303.9 |
| G5 | loiacono | 24 | 754.42 | 783.99 | -66.7 | 162.3 | -300.0 to +275.0 |
| G5 | librosa | 24 | 820.52 | 783.99 | +77.5 | 239.9 | -302.7 to +311.1 |
| A5 | loiacono | 24 | 877.20 | 880.00 | -5.5 | 132.4 | -300.0 to +275.0 |
| A5 | librosa | 24 | 891.52 | 880.00 | +22.5 | 176.3 | -311.7 to +305.8 |
| B5 | loiacono | 24 | 1035.58 | 987.77 | +81.8 | 133.5 | -231.7 to +275.0 |
| B5 | librosa | 24 | 816.67 | 987.77 | -329.3 | 189.3 | -329.3 to +325.2 |
| C6 | loiacono | 24 | 1090.71 | 1046.50 | +71.6 | 97.2 | -48.0 to +275.0 |
| C6 | librosa | 24 | 864.71 | 1046.50 | -330.4 | 264.5 | -330.4 to +321.4 |
| D6 | loiacono | 24 | 1199.57 | 1174.66 | +36.3 | 48.9 | -14.1 to +175.0 |
| D6 | librosa | 24 | 980.00 | 1174.66 | -313.7 | 128.9 | -313.7 to +331.5 |
| E6 | loiacono | 24 | 1331.66 | 1318.51 | +17.2 | 89.9 | -279.0 to +300.0 |
| E6 | librosa | 24 | 1102.50 | 1318.51 | -309.8 | 123.4 | -309.8 to +307.7 |
| F#6 | loiacono | 24 | 1522.90 | 1479.98 | +49.5 | 64.2 | -164.7 to +171.0 |
| F#6 | librosa | 24 | 1225.00 | 1479.98 | -327.4 | 271.0 | -327.4 to +303.9 |
| G6 | loiacono | 24 | 1567.70 | 1567.98 | -0.3 | 127.5 | -278.5 to +275.0 |
| G6 | librosa | 24 | 1624.28 | 1567.98 | +60.5 | 324.5 | -328.4 to +348.3 |

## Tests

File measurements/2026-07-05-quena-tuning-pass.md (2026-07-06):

# 2026-07-05 quena tuning pass

Source reading: tune check from `20260705.wav`.

## Current readings pasted before this pass

| detected note | frames | median Hz | target Hz | median cents | meaning |
| --- | ---: | ---: | ---: | ---: | --- |
| G4 | 202 | 392.86 | 392.00 | +3.8 | in tune |
| A4 | 188 | 438.43 | 440.00 | -6.2 | flat |
| A#4 | 87 | 478.11 | 466.16 | +43.8 | sharp |
| B4 | 63 | 480.88 | 493.88 | -46.2 | flat |
| C5 | 170 | 518.38 | 523.25 | -16.2 | flat |
| C#5 | 2 | 552.47 | 554.37 | -6.2 | flat |
| D5 | 138 | 585.24 | 587.33 | -6.2 | flat |
| E5 | 170 | 656.91 | 659.26 | -6.2 | flat |
| F#5 | 132 | 733.11 | 739.99 | -16.2 | flat |
| G5 | 391 | 781.20 | 783.99 | -6.2 | flat |
| G#4 | 8 | 407.89 | 415.30 | -31.2 | flat |

## Local rerun with current script

Command: `python3 tunecheck.py 20260705.wav`

| detected note | frames | median Hz | target Hz | median cents | meaning |
| --- | ---: | ---: | ---: | ---: | --- |
| G4 | 202 | 391.70 | 392.00 | -1.3 | in tune |
| A4 | 188 | 439.67 | 440.00 | -1.3 | in tune |
| A#4 | 116 | 479.46 | 466.16 | +48.7 | sharp |
| B4 | 34 | 482.24 | 493.88 | -41.3 | flat |
| C5 | 170 | 516.85 | 523.25 | -21.3 | flat |
| C#5 | 2 | 550.84 | 554.37 | -11.3 | flat |
| D5 | 138 | 583.50 | 587.33 | -11.3 | flat |
| E5 | 170 | 658.75 | 659.26 | -1.3 | in tune |
| F#5 | 132 | 730.93 | 739.99 | -21.3 | flat |
| G5 | 392 | 783.39 | 783.99 | -1.3 | in tune |
| G#4 | 9 | 407.86 | 415.30 | -31.3 | flat |

## Interpretation

G4 is the all-closed/open-end reference and is already in tune enough, so the overall acoustic length was left unchanged. The two accidental detections, A#4 and C#5, had either ambiguous pitch identity or very few frames, so they were not treated as target notes for geometry.

B4 was the outlier. The A#4 cluster is very close to the B4 frequency, so the B correction is intentionally larger than the other holes but still conservative enough to avoid a likely overshoot.

## Geometry changes

All hole positions below are the acoustic values inside `tuned_length(...)`, not the final OpenSCAD z coordinate. Lower values move the hole closer to the blowing edge and raise pitch.

| hole | before position | after position | before diameter | after diameter | reason |
| --- | ---: | ---: | ---: | ---: | --- |
| A | 342.00 | 341.00 | 10.00 | 10.10 | A4 was 6.2 cents flat |
| B | 307.25 | 302.75 | 10.00 | 10.35 | B4 was 46.2 cents flat; conservative revision from the first larger move |
| C | 281.75 | 279.25 | 9.50 | 9.75 | C5 was 16.2 cents flat |
| D | 246.50 | 245.50 | 11.00 | 11.10 | D5 was 6.2 cents flat |
| E | 215.00 | 214.15 | 11.00 | 11.10 | E5 was 6.2 cents flat |
| F# | 188.00 | 186.20 | 10.88 | 11.13 | F#5 was 16.2 cents flat |

## Next comparison

After the next print, run the same tune check and compare the new median cents against the table above. The main pass/fail questions are:

- Does B4 move substantially upward without becoming sharp?
- Do the A#4 frames collapse into a stable B4 detection?
- Do C5 and F#5 move closer to center without making G4 drift?

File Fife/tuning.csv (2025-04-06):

Expected_Note | Expected_Frequency | Actual_Frequency_StockIn_1_5cm | Actual_Frequency_StockOut | Actual_Frequency_StockIn_Ext
A4 | 440.0 | 460 | 464 | 442
B4 | 493.88 | 497 | 505 | 497
C#4 | 554.37 | 538 | 543 | 539
D4 | 587.33 | 582 | 588 | 587
E4 | 659.25 | 644 | 652 | 650
F#4 | 739.99 | 714 | 721 | 726
G#4 | 830.61 | 798 | 796 | 816
A5 | 880.0 | 915 | 910 | 870

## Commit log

2020-05-12 stl split by parts included
    [Quena.stl, QuenaPart1.stl, QuenaPart2.stl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]
2024-12-10 now tuned to G
    [Quena.scad, Quena.stl]
2024-12-10 4th attempt. increased bezel angle slightly. retuned holes mildly
    [Quena.scad, Quena.stl]
2024-12-12 mild adj for tuning and playability. print #5
    [Quena.scad]
2025-02-28 adds epsilon for easier viewing
    [Quena.scad]
2025-03-08 10, with taper
    [Quena.scad, Quena.stl]
2025-03-09 10 as printed
    [Quena.scad, Quena.stl]
2025-03-12 removes quena taper, adds low whistle draft
    [LowWhistle.scad, Quena.scad]
2025-03-27 mild tuning adjustments
    [Quena.scad, Quena.stl]
2025-03-29 as printed and cut
    [EndCap.scad, EndCap.stl]
2025-04-01 i started making parts that can modify the fife in post
    [PipeExtension.scad, PipeExtension.stl, tuning.csv]
2025-04-06 adds tuning plot with extension
    [tuning.csv]
2025-04-06 attempted revert and F# correction of Print #8
    [Quena.scad, Quena.stl]
2025-04-10 tried to fix it. broke it instead
    [Quena.scad, Quena.stl]
2025-04-11 still broke :)
    [Quena.scad]
2025-04-11 major fixes. battery might die?
    [Quena.scad]
2025-04-11 8C as printed at the Node
    [Quena.scad]
2025-04-11 adds stl
    [Quena.stl]
2025-05-06 first fipple "eurasian synergy" edition, as printed
    [Quena.scad, Quena.stl]
2025-05-08 another fipple, as printed
    [FippleAttempts.scad, Quena.scad, Quena.stl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]
2025-05-09 as printed
    [fipple02.scad, fipple02.stl]
2025-10-19 4-parter, as printed
    [Quena.scad, Quena.stl, Quena_fit_test.stl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]
2025-11-25 characterizes the frequencies; evidently PETG runs much flatter, or expends sightly less on the bambu
    [Quena.scad]
2026-03-27 this could be it
    [Quena.3mf, Quena.scad, Quena.stl]
2026-07-02 idk latest
    [Quena.scad, Quena.stl, QuenaCase.scad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]
2026-07-05 Redesign quena case latch and retention
    [QuenaCase.scad, QuenaCaseAssembly.stl, QuenaCaseBottom.stl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]
2026-07-06 Tune quena hole geometry
    [Quena.scad, geometry_by_commit.csv, holes_by_commit.csv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]
2026-07-06 Add assembled quena acoustic simulation
    [Quena.scad, assembled_air.scad, assembled_quena.scad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]
2026-07-10 Add snap-fit quena case
    [Quena.3mf, QuenaCase.scad, QuenaCaseAssembly.stl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]
2026-07-11 This is the cantilever style. Pushing now and printing because I'm interested to see how it works. However, I'm going to move to a more friction fit cantileverless next.
    [QuenaCase.scad, QuenaCaseAssembly.stl, QuenaCaseBottom.stl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]
2026-07-12 As printed out.
    [Quena.scad, Quena.stl, QuenaCase.scad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]
2026-07-12 I have a test.
    [2026-07-12-134806-0400-guided-tuning.csv, 2026-07-12-134829-0400-guided-tuning.csv, Quena.scad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]
2026-07-15 As printed, let's see how this case is.
    [QuenaCase.scad, QuenaCaseAssembly.stl, QuenaCaseBottom.stl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]
2026-07-22 About to adjust mouthpiece, maybe?
    [Quena.scad, QuenaCase.3mf]
2026-07-22 Gotta print this as soon as I get my ass up and turn the printer on.
    [EndCap.scad, EndCap.stl, PipeExtension.stl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]
2026-07-29 Retune quena and add WebGPU acoustic lab
    [2026-07-27-210414-0400-guided-tuning.csv, 2026-07-27-210508-0400-guided-tuning.csv, Quena.3mf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]
2026-08-01 Refine quena geometry and snap-over case
    [2026-07-31-212538-0400-guided-tuning.csv, Quena.3mf, Quena.stl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]
2026-08-02 Refine quena fit, case, and acoustic lab
    [Quena.scad, QuenaCase.scad, QuenaCaseAssembly.stl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]
2026-08-02 Package two-color case and model live jet response
    [QuenaCase.3mf, QuenaCase.scad, QuenaCaseAssembly.stl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]
2026-08-02 Refine two-color case and acoustic player model
    [QuenaCase.3mf, QuenaCase.scad, QuenaCaseArtwork.stl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]
2026-08-02 Refresh shortened case review sheets
2026-08-02 Refine case and automate print slicing
    [Quena.3mf, Quena.stl, QuenaCase.3mf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]
2026-08-03 Add single-filament case export
    [QuenaCase.3mf, QuenaCaseAssembly.stl, QuenaCaseBottomViewer.stl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]
2026-08-03 Retune quena and refine case production
    [2026-08-03-160409-0400-guided-tuning.csv, Quena.3mf, Quena.stl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]
2026-08-04 Correct quena hole tuning
    [Quena.gcode.3mf, QuenaCase.3mf, QuenaCase.gcode.3mf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]
2026-08-18 Angle both tube joint radius transitions
    [Quena.scad]
2026-08-18 Add one-shot STL regeneration workflow
2026-08-18 Probe GitHub Actions availability
2026-08-18 Remove temporary Actions probe
2026-08-18 Make STL regeneration observable and rebase-safe
2026-08-18 Link STL regeneration status to workflow logs
